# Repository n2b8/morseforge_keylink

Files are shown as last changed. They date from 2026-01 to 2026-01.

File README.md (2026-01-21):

# MorseForge Keylink

**Keylink** is an open‑source hardware adapter that makes traditional Morse keys Bluetooth‑capable.

It is designed and maintained by the **MorseForge developer** as a companion device for upcoming external‑key features in the **MorseForge** app.

🌐 **MorseForge:** https://morseforge.com

---

## What is Keylink?

Keylink bridges classic Morse key hardware with modern Bluetooth‑enabled devices. It allows straight keys, paddles, and other traditional Morse inputs to transmit key events wirelessly using Bluetooth Low Energy (BLE).

Keylink is intended to:
- Enable wireless Morse key input
- Integrate directly with future MorseForge app features
- Remain compact, battery‑powered, and easy to assemble
- Be fully open source and community‑friendly

Unlike generic microcontroller dev boards, Keylink is a **purpose‑built Morse interface**.

---

## Hardware Overview — Rev B

The current hardware revision (Rev B) includes:

- **ESP32‑C3 microcontroller (Seeed XIAO form factor)**
- **3.5 mm stereo jack (SJ1‑3523N)** for Morse key input
- **Slide power switch** for battery isolation
- **JST‑PH 2.0 mm battery connector**
- LiPo battery support
- Passive input conditioning network

This revision has been fabricated via OSH Park and is undergoing validation.

---

## PCB Renders (Rev B)

### Top View
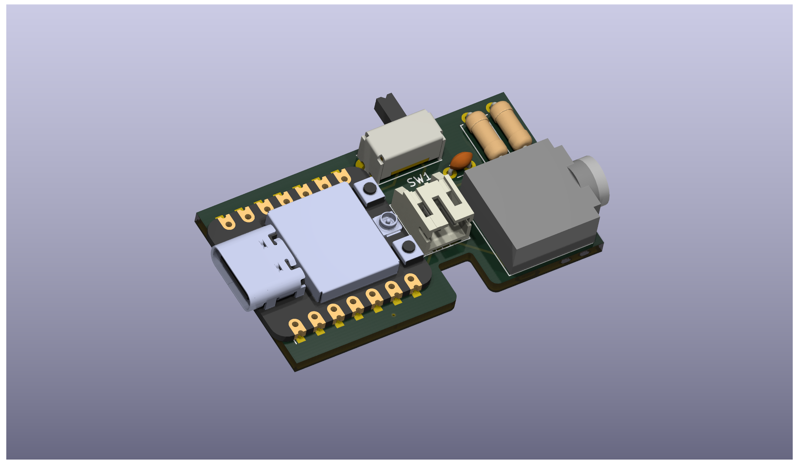
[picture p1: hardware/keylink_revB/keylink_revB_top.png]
Keylink Rev B Top


### Bottom View
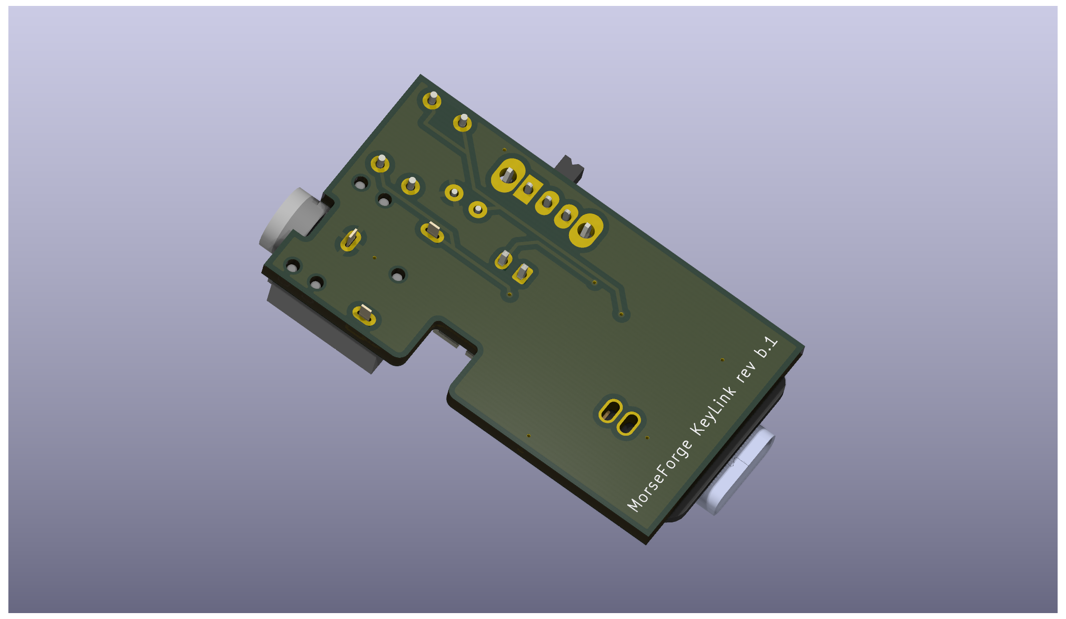
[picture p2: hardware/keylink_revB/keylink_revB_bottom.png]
Keylink Rev B Bottom


> Renders generated from KiCad’s 3D viewer. These are not production photographs.

---

## Repository Structure

```
hardware/
├── keylink_revB/     # KiCad schematic + PCB layout
├── gerber/           # Manufacturing Gerbers
mobile_app/           # React Native example app
software/             # Firmware (Arduino + legacy)
```

Additional firmware and software directories will be added as development progresses.

---

## Firmware & App Integration

Keylink firmware now uses the Arduino framework and exposes the device as a BLE
HID keyboard for Vail Adapter compatibility. The sketch lives at:
`software/keylink_ble_keyboard/keylink_ble_keyboard.ino`.

Key events:
- DIT (left paddle) sends Ctrl + [
- DAH (right paddle) sends Ctrl + ]

### Flashing (Arduino)

1. Install Arduino IDE and the ESP32 board package.
2. Install the "ESP32 BLE Keyboard" library (T-vK).
3. Open `software/keylink_ble_keyboard` in Arduino IDE.
4. Select board "Seeed XIAO ESP32C3" and flash.
5. Pair the device as "Keylink" in your OS Bluetooth settings.

The prior CircuitPython UART firmware remains at `software/code.py` for
reference but is not Vail-compatible.

---

## Open Source

This project is released as open‑source hardware and software.

Licensing details will be finalized and documented explicitly, but the intent is:
- **Permissive open hardware**
- **Permissive firmware licensing**
- Community contributions welcome

---

## Disclaimer

This is experimental hardware.

No warranties are provided.  
Use at your own risk.

---

## Author

Keylink is designed and maintained by the **MorseForge developer** as part of the broader MorseForge ecosystem.

🌐 https://morseforge.com

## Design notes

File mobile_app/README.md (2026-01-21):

# MorseForge Keylink Mobile App

Expo React Native app for receiving Morse key input from a BLE HID keyboard
(Keylink) and playing sidetone audio.

## Features

- External keyboard input (Ctrl+[ / Ctrl+]) from Keylink
- Real-time audio sidetone playback
- Straight + iambic keyer modes
- Event logging

## Setup

### 1. Install Dependencies

```bash
cd mobile_app
npm install
```

### 2. Run on iOS (Physical Device Required)

```bash
npx expo run:ios
```

**Note:** This app uses a native module (`react-native-external-keyboard`), so
Expo Go will not work. Use a dev build (see `BUILDING.md`).

### 3. Flash your Keylink device

Flash the Arduino firmware from:
`../software/keylink_ble_keyboard/keylink_ble_keyboard.ino`

### 4. Connect

1. Pair Keylink in your phone's Bluetooth settings (it appears as "Keylink").
2. Open the app and tap **Focus Input** if needed.
3. Press the paddles to hear tones.

## Configuration

### Keyer Modes

The app supports three keyer modes:
- **Straight Key**: Both paddles act as a simple straight key (continuous tone while pressed)
- **Iambic A**: Automatic alternating dits and dahs with paddle squeeze
- **Iambic B**: Enhanced iambic mode with improved squeeze behavior

Switch modes using the mode selector buttons in the app.

### Input Protocol

The firmware sends BLE HID key combos:
- DIT (left paddle): **Ctrl + [**
- DAH (right paddle): **Ctrl + ]**

The app listens for these external keyboard events using
`react-native-external-keyboard`.

### Tone Timing

Edit `App.js` to adjust:
- `DIT_MS = 60` - Duration of dit tone (milliseconds)
- `DAH_MS = 180` - Duration of dah tone (milliseconds)

## Building for Production

### iOS

1. Install EAS CLI:
```bash
npm install -g eas-cli
```

2. Configure EAS:
```bash
eas build:configure
```

3. Build for iOS:
```bash
eas build --platform ios
```

### Android

```bash
eas build --platform android
```

## Troubleshooting

### No key events
- Ensure Keylink is paired as a Bluetooth keyboard in system settings
- Tap **Focus Input** in the app to regain keyboard focus
- Verify the firmware is flashed and powered on

### No audio on key press
- Check phone is not in silent mode (iOS)
- Ensure `assets/tone.wav` exists
- Check console for audio initialization errors

## Project Structure

```
mobile_app/
├── App.js           # Main application code
├── app.json         # Expo configuration
├── package.json     # Dependencies
├── assets/
│   └── tone.wav     # Sidetone audio file
└── README.md        # This file
```

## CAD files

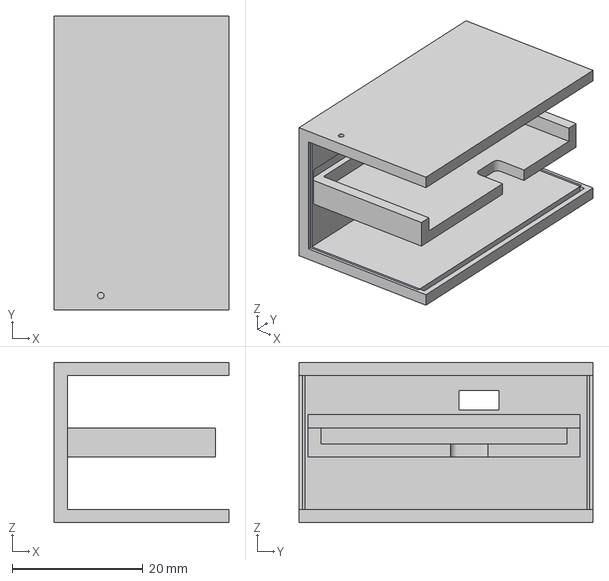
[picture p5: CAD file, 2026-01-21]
hardware/enclosure/printfiles/revB_case/Main_Housing.3mf
26.7 x 45.0 x 24.5 mm

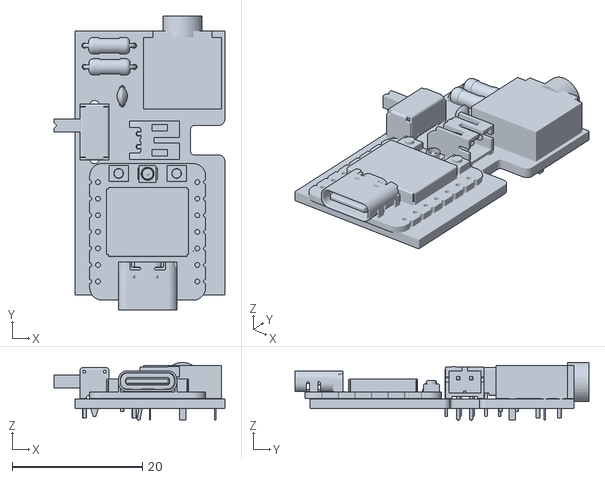
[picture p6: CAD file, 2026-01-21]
hardware/enclosure/keylink_revB.stl
26.2 x 45.1 x 8.90

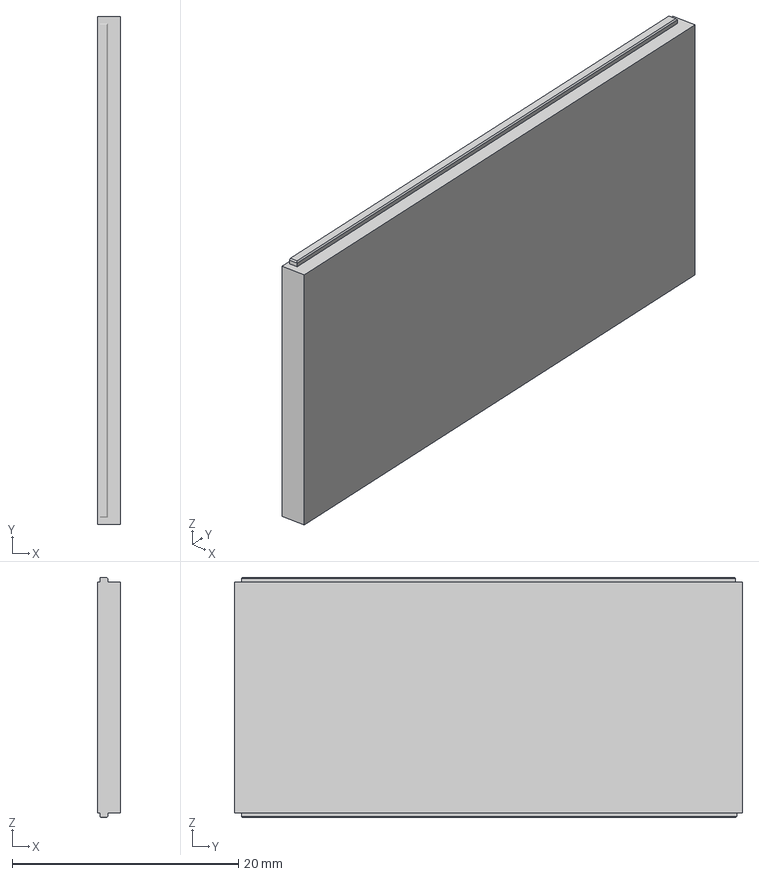
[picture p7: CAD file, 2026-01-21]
hardware/enclosure/printfiles/revB_case/Back.3mf
2.00 x 45.0 x 21.3 mm

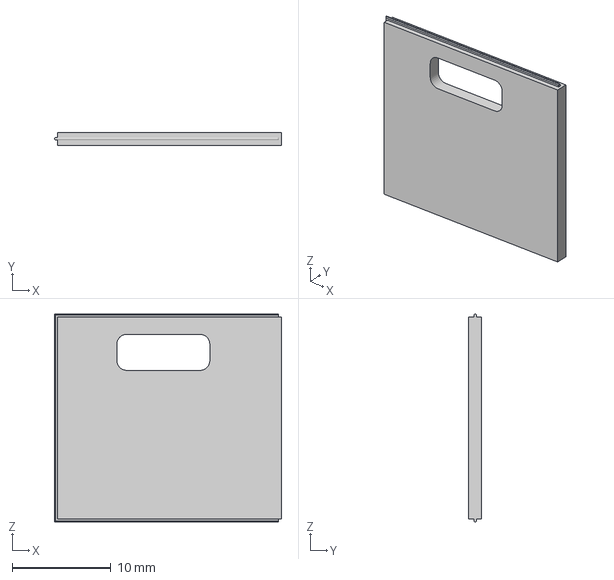
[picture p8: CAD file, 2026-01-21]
hardware/enclosure/printfiles/revB_case/USB_Side.3mf
23.0 x 1.35 x 21.1 mm

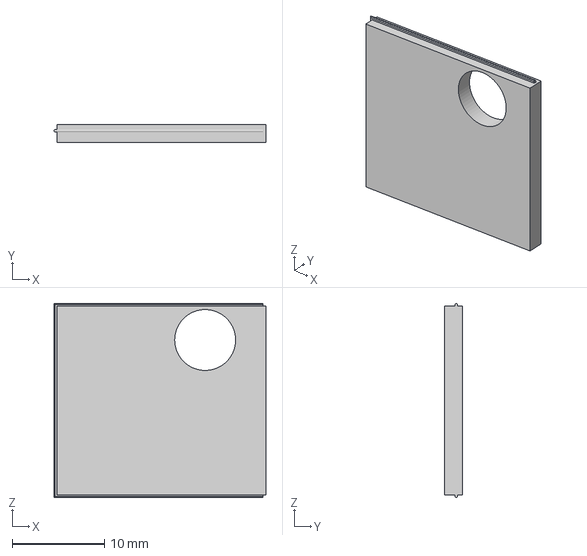
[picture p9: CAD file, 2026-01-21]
hardware/enclosure/printfiles/revB_case/TRS_Side.3mf
23.0 x 1.97 x 21.1 mm

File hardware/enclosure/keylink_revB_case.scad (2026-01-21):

// Keylink RevB - Parametric enclosure (Rev A)
// Units: mm

$fn = 48;

// -------------------- PARAMETERS --------------------
pcb_len = 40.0;        // measure from STEP
pcb_wid = 23.0;        // measure from STEP
pcb_thk = 1.6;

wall = 2.0;
floor = 2.0;

// Clearance
pcb_side_clear = 0.30; // per side
pcb_z_clear = 1.0;     // space above PCB plane before lid
rail_lip = 1.0;        // how much rail overlaps PCB edge
rail_height = pcb_thk + 0.3; // rail height above base floor

// Divider deck separating PCB and battery
deck_thk = 1.8;
deck_gap = 0.6;        // clearance between battery and deck (air gap)
pcb_to_deck = 1.0;     // space under PCB before deck (wires, solder)

// Battery (your candidate: 31 x 25 x 7)
bat_len = 31.0;
bat_wid = 25.0;
bat_thk = 7.0;
bat_clear_xy = 0.5;
bat_clear_z = 0.6;

// Case outer size
inner_len = pcb_len + 2*pcb_side_clear;
inner_wid = pcb_wid + 2*pcb_side_clear;

// Heights
pcb_plane_z = floor + pcb_to_deck + deck_thk + deck_gap + bat_thk + bat_clear_z;
inner_height = pcb_plane_z + pcb_thk + pcb_z_clear;   // interior height above floor
outer_height = inner_height + wall;

// End cutouts (placeholders - measure from STEP)
// USB-C at one end:
usbc_w = 10.0;
usbc_h = 4.0;
usbc_y_off = 0.0;      // offset from centerline if needed
// Audio jack at the other end:
jack_w = 8.0;
jack_h = 8.0;
jack_y_off = 0.0;

// Light pipe hole (measure LED XY from STEP)
// Coordinates relative to PCB origin at inside corner of case
led_x = 10.0;
led_y = 0.0;
lightpipe_d = 3.2;

// Battery side insert slot
slot_h = bat_thk + bat_clear_z + 1.0;
slot_w = bat_wid + bat_clear_xy;
slot_z = floor + 1.0; // from bottom

// -------------------- HELPERS --------------------
module rounded_box(x,y,z,r=2.0) {
  minkowski() {
    cube([x-2*r, y-2*r, z-2*r], center=false);
    sphere(r=r);
  }
}

module shell_base() {
  difference() {
    // Outer body
    rounded_box(inner_len + 2*wall, inner_wid + 2*wall, outer_height, r=2.0);

    // Hollow interior
    translate([wall, wall, floor])
      cube([inner_len, inner_wid, outer_height], center=false);
  }
}

module pcb_rails() {
  // Rails run along the long edges (length direction)
  // They form a channel the PCB slides into.
  rail_y0 = wall + pcb_side_clear;
  rail_y1 = wall + inner_wid - pcb_side_clear;

  // Left rail
  translate([wall, rail_y0 - rail_lip, pcb_plane_z])
    cube([inner_len, rail_lip, rail_height], center=false);

  // Right rail
  translate([wall, rail_y1, pcb_plane_z])
    cube([inner_len, rail_lip, rail_height], center=false);
}

module divider_deck() {
  // Deck across most of the case, leaving a battery region below
  translate([wall, wall, floor + pcb_to_deck])
    cube([inner_len, inner_wid, deck_thk], center=false);
}

module battery_pocket_cut() {
  // Pocket below the deck
  pocket_len = bat_len + bat_clear_xy;
  pocket_wid = bat_wid + bat_clear_xy;
  pocket_thk = bat_thk + bat_clear_z;

  // Put battery pocket centered, adjust if needed
  px = wall + (inner_len - pocket_len)/2;
  py = wall + (inner_wid - pocket_wid)/2;
  pz = floor;

  translate([px, py, pz])
    cube([pocket_len, pocket_wid, pocket_thk], center=false);
}

module battery_side_slot_cut() {
  // Slot through the case wall into battery pocket
  // Default: slot on the "right" side wall
  x0 = wall + (inner_len - (bat_len + bat_clear_xy))/2;
  y_wall = inner_wid + wall; // outer right wall
  z0 = slot_z;

  translate([x0, y_wall - 0.01, z0])
    cube([bat_len + bat_clear_xy, wall + 0.02, slot_h], center=false);
}

module end_cutouts() {
  // USB-C at +X end (front)
  translate([wall + inner_len - 0.01, wall + inner_wid/2 - usbc_w/2 + usbc_y_off, pcb_plane_z + pcb_thk/2 - usbc_h/2])
    cube([wall + 0.02, usbc_w, usbc_h], center=false);

  // Audio jack at -X end (back)
  translate([-0.01, wall + inner_wid/2 - jack_w/2 + jack_y_off, pcb_plane_z + pcb_thk/2 - jack_h/2])
    cube([wall + 0.02, jack_w, jack_h], center=false);
}

module lightpipe_cut() {
  // Hole through the lid area above the LED
  // LED position measured from inside corner (same orientation as PCB placement)
  lx = wall + pcb_side_clear + led_x;
  ly = wall + pcb_side_clear + led_y;
  lz = pcb_plane_z + pcb_thk + pcb_z_clear/2;

  translate([lx, ly, lz])
    rotate([90,0,0])
      cylinder(d=lightpipe_d, h=inner_wid + 2*wall, center=true);
}

// -------------------- BUILD --------------------
difference() {
  union() {
    shell_base();
    divider_deck();
    pcb_rails();
  }

  // Remove battery pocket volume
  battery_pocket_cut();

  // Battery insert slot
  battery_side_slot_cut();

  // End cutouts
  end_cutouts();

  // Lightpipe hole
  lightpipe_cut();
}

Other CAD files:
hardware/keylink_revB/keylink_revB.step
hardware/enclosure/U_Box_V104_Test_Cleaned.scad

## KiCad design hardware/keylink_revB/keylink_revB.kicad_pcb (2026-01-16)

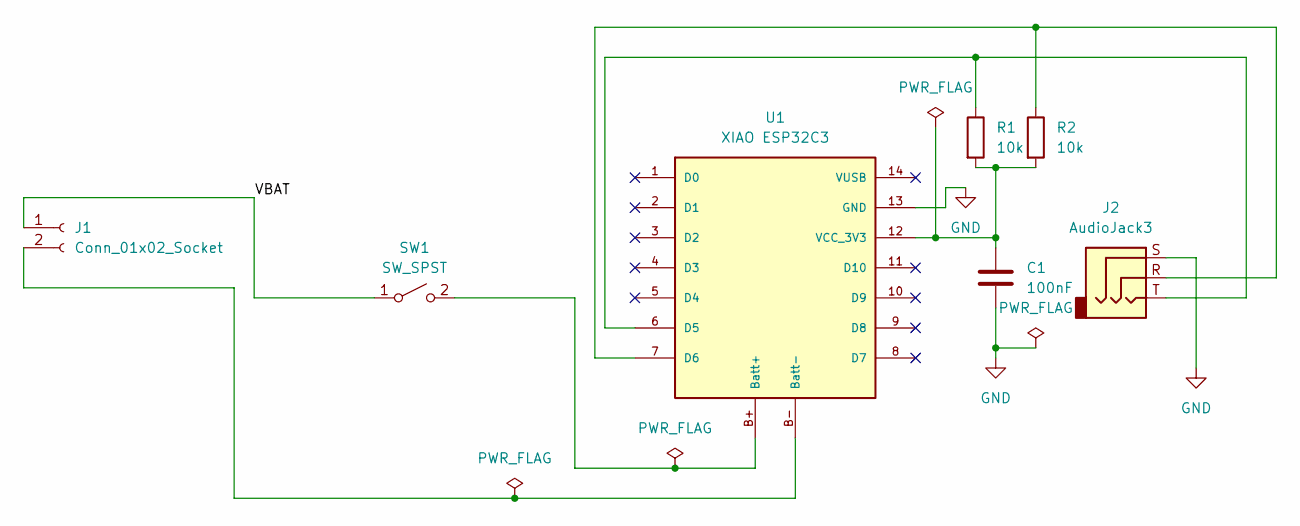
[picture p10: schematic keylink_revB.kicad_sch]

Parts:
C1: 100nF; C_Disc_D3.0mm_W1.6mm_P2.50mm
J1: Conn_01x02_Socket; JST_PH_S2B-PH-K_1x02_P2.00mm_Horizontal
J2: AudioJack3; Jack_3.5mm_CUI_SJ1-3523N_Horizontal
R1, R2: 10k; R_Axial_DIN0207_L6.3mm_D2.5mm_P7.62mm_Horizontal
SW1: SW_SPST; SW_Slide_SPDT_Angled_CK_OS102011MA1Q
U1: XIAO ESP32C3; xiao_esp32c3

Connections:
/VBAT: J1.1, SW1.1 (A)
GND: C1.2, J2.S, U1.13 (GND)
unnamed: J1.2, U1.B- (Batt-)
unnamed: SW1.2 (B), U1.B+ (Batt+)
unnamed: J2.T, R1.1, U1.6 (D5)
unnamed: J2.R, R2.1, U1.7 (D6)
unnamed: C1.1, R1.2, R2.2, U1.12 (VCC_3V3)

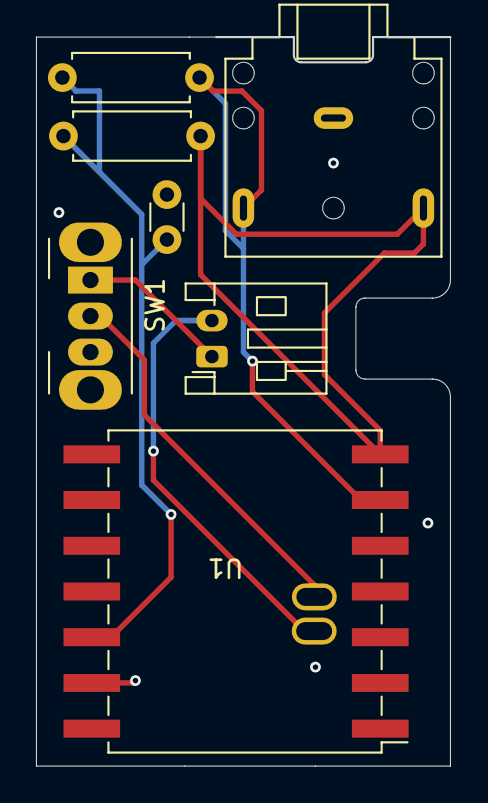
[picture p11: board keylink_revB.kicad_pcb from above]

Board: 2 copper layers, 23.0 x 40.5 mm, 7 parts (0 on the bottom side), 7 nets.

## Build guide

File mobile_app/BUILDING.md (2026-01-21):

# Building MorseForge Keylink for iOS and Android

Since this app uses native modules (external keyboard support), you cannot use
Expo Go. You need to create a development build.

## Option 1: Build Locally with Xcode (Recommended for Testing)

### Prerequisites
- Xcode installed
- iOS development certificate
- Your iPhone connected via USB

### Steps

1. Install iOS dependencies:
```bash
cd mobile_app
npx expo prebuild
```

2. Open the iOS project in Xcode:
```bash
open ios/mobileapp.xcworkspace
```

3. In Xcode:
   - Select your connected iPhone as the target device
   - Select your development team in Signing & Capabilities
   - Click the Play button to build and run

4. The app will install on your iPhone

## Option 2: Build with EAS (For Production)

### Prerequisites
- Expo account (free)
- EAS CLI installed

### Steps

1. Install EAS CLI:
```bash
npm install -g eas-cli
```

2. Login to Expo:
```bash
eas login
```

3. Configure EAS:
```bash
eas build:configure
```

4. Create a development build:
```bash
eas build --profile development --platform ios
```

5. When complete, scan the QR code with your iPhone to install

## Option 3: Quick Test with Expo Dev Client

1. Install expo-dev-client:
```bash
npx expo install expo-dev-client
```

2. Start development:
```bash
npx expo start --dev-client
```

3. Follow on-screen instructions to build and install on your device

## Android (Physical Device Required for External Keyboard Input)

1. Install dependencies:
```bash
cd mobile_app
npm install
```

2. Build and install on a connected device:
```bash
npx expo run:android
```

3. Pair Keylink as a Bluetooth keyboard in system settings

## Troubleshooting

### "Signing requires a development team"
- In Xcode, go to Signing & Capabilities
- Select your Apple ID team
- Xcode will automatically create a provisioning profile

### "Unable to install"
- Make sure your iPhone trusts your Mac
- Check that Developer Mode is enabled on iOS 16+ (Settings > Privacy & Security > Developer Mode)

### No key events
- Ensure Keylink is paired and connected as a keyboard
- Tap **Focus Input** in the app to regain keyboard focus

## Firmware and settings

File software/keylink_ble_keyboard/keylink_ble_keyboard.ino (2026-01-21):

#define USE_NIMBLE
#include <BleKeyboard.h>

// Keylink Rev B (Seeed XIAO ESP32C3)
// TRRS tip (left) -> GPIO7 (D5)
// TRRS ring (right) -> GPIO21 (D6)
const int DIT_PIN = 7;
const int DAH_PIN = 21;
const uint32_t DEBOUNCE_MS = 10;

const char DIT_KEY = '[';
const char DAH_KEY = ']';

BleKeyboard bleKeyboard("Keylink", "MorseForge", 100);

bool lastDitState = true;
bool lastDahState = true;
uint32_t lastDitChange = 0;
uint32_t lastDahChange = 0;

bool ditPressed = false;
bool dahPressed = false;
bool ctrlHeld = false;
bool lastConnected = false;

void resetKeyState() {
  ditPressed = false;
  dahPressed = false;
  ctrlHeld = false;
  bleKeyboard.releaseAll();
}

void applyConnectionState(bool connected) {
  if (connected == lastConnected) {
    return;
  }
  lastConnected = connected;
  if (!connected) {
    resetKeyState();
  }
}

void sendComboDown(char key) {
  if (!bleKeyboard.isConnected()) {
    return;
  }
  if (!ctrlHeld) {
    bleKeyboard.press(KEY_LEFT_CTRL);
    ctrlHeld = true;
  }
  bleKeyboard.press(key);
}

void sendComboUp(char key) {
  if (!bleKeyboard.isConnected()) {
    return;
  }
  bleKeyboard.release(key);
  if (!ditPressed && !dahPressed && ctrlHeld) {
    bleKeyboard.release(KEY_LEFT_CTRL);
    ctrlHeld = false;
  }
}

void setup() {
  Serial.begin(115200);
  pinMode(DIT_PIN, INPUT_PULLUP);
  pinMode(DAH_PIN, INPUT_PULLUP);
  bleKeyboard.begin();
}

void loop() {
  const bool connected = bleKeyboard.isConnected();
  applyConnectionState(connected);

  const uint32_t now = millis();

  const bool ditState = digitalRead(DIT_PIN);
  if (ditState != lastDitState && (now - lastDitChange) >= DEBOUNCE_MS) {
    lastDitChange = now;
    lastDitState = ditState;
    if (!ditState) {
      ditPressed = true;
      sendComboDown(DIT_KEY);
    } else {
      ditPressed = false;
      sendComboUp(DIT_KEY);
    }
  }

  const bool dahState = digitalRead(DAH_PIN);
  if (dahState != lastDahState && (now - lastDahChange) >= DEBOUNCE_MS) {
    lastDahChange = now;
    lastDahState = dahState;
    if (!dahState) {
      dahPressed = true;
      sendComboDown(DAH_KEY);
    } else {
      dahPressed = false;
      sendComboUp(DAH_KEY);
    }
  }

  delay(1);
}

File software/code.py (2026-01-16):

import time
import board
import digitalio

# BLE imports - requires adafruit_ble from the CircuitPython bundle
try:
    from adafruit_ble import BLERadio
    from adafruit_ble.advertising.standard import ProvideServicesAdvertisement
    from adafruit_ble.services.nordic import UARTService
    BLE_AVAILABLE = True
except ImportError:
    BLE_AVAILABLE = False
    print("WARNING: BLE libraries not found. Install adafruit_ble library bundle.")

# ----------------------------
# CONFIG (XIAO ESP32C3 PIN MAP)
# ----------------------------
# TRRS tip (left) -> GPIO7 (board.D5)
# TRRS ring (right) -> GPIO21 (board.D6)
DIT_PIN = board.D5     # TRRS TIP / left (GPIO7)
DAH_PIN = board.D6     # TRRS RING / right (GPIO21)
DEBOUNCE_S = 0.010     # 10ms debounce

# ----------------------------
# Optional onboard NeoPixel (no neopixel module needed)
# ----------------------------
PIXEL_ENABLED = True
PIXEL_PIN = getattr(board, "NEOPIXEL", None)
_pixel_io = None
_pixel_ok = False

def pixel_init():
    global _pixel_io, _pixel_ok
    if not PIXEL_ENABLED:
        return
    if PIXEL_PIN is None:
        return
    try:
        import neopixel_write  # type: ignore
        _pixel_io = digitalio.DigitalInOut(PIXEL_PIN)
        _pixel_io.direction = digitalio.Direction.OUTPUT
        _pixel_ok = True
    except Exception:
        _pixel_ok = False

def pixel_set(r: int, g: int, b: int):
    """Set pixel color. Most NeoPixels are GRB order."""
    if not _pixel_ok or not PIXEL_ENABLED:
        return
    import neopixel_write  # type: ignore
    r = max(0, min(255, r))
    g = max(0, min(255, g))
    b = max(0, min(255, b))
    neopixel_write.neopixel_write(_pixel_io, bytes([g, r, b]))

def pixel_off():
    pixel_set(0, 0, 0)

def ms() -> int:
    return int(time.monotonic() * 1000)

# ----------------------------
# Setup inputs (active-low with pullups)
# ----------------------------
dit = digitalio.DigitalInOut(DIT_PIN)
dit.direction = digitalio.Direction.INPUT
dit.pull = digitalio.Pull.UP

dah = digitalio.DigitalInOut(DAH_PIN)
dah.direction = digitalio.Direction.INPUT
dah.pull = digitalio.Pull.UP

last_dit = dit.value
last_dah = dah.value
last_change_dit = time.monotonic()
last_change_dah = time.monotonic()

pixel_init()
pixel_set(0, 0, 12)  # dim blue idle (if pixel is available)

# ----------------------------
# BLE Setup
# ----------------------------
ble = None
uart = None
advertisement = None
if BLE_AVAILABLE:
    ble = BLERadio()
    ble.name = "MorseKey"
    uart = UARTService()
    advertisement = ProvideServicesAdvertisement(uart)
    # Keep the device name in the primary advertisement for iOS discovery.
    advertisement.complete_name = ble.name
    print(f"Advertisement services: {advertisement.services}")

last_connected = False
last_uart_error = 0.0

def ble_is_connected() -> bool:
    return bool(BLE_AVAILABLE and ble and ble.connected)

def safe_uart_write(event_text: str) -> None:
    global last_uart_error
    if not ble_is_connected():
        return
    try:
        uart.write((event_text + "\n").encode("utf-8"))
    except Exception as exc:
        now = time.monotonic()
        if (now - last_uart_error) > 2.0:
            print("UART write failed:", repr(exc))
            last_uart_error = now

print("=== MorseForge TRRS + BLE (Seeed XIAO ESP32C3) ===")
print("DIT pin:", DIT_PIN)
print("DAH pin:", DAH_PIN)
print("Debounce:", int(DEBOUNCE_S * 1000), "ms")
if BLE_AVAILABLE:
    print("BLE Name:", ble.name)
    print("Starting BLE advertising...")
    ble.start_advertising(advertisement)
    print("Ready. Press paddles/key...")
else:
    print("BLE not available - running in serial-only mode")
    print("Ready. Press paddles/key...")

# ----------------------------
# Main loop
# ----------------------------
while True:
    now = time.monotonic()

    # Check for BLE connection changes
    if BLE_AVAILABLE and ble:
        connected_now = ble.connected
        if connected_now != last_connected:
            last_connected = connected_now
            if connected_now:
                print("BLE connected.")
                pixel_set(12, 0, 12)  # purple = connected
            else:
                print("BLE disconnected.")
                if not ble.advertising:
                    print("Restarting BLE advertising...")
                    ble.start_advertising(advertisement)
                pixel_set(0, 0, 12)  # idle blue

    # DIT edge detect with debounce
    cur_dit = dit.value
    if cur_dit != last_dit and (now - last_change_dit) >= DEBOUNCE_S:
        last_change_dit = now
        last_dit = cur_dit

        if not cur_dit:
            # Key pressed (active low)
            event = "K1:1"  # Key 1 (dit/left paddle) pressed
            print(f"{ms()} DIT_DOWN")
            pixel_set(0, 20, 0)   # green
            safe_uart_write(event)
        else:
            # Key released
            event = "K1:0"  # Key 1 (dit/left paddle) released
            print(f"{ms()} DIT_UP")
            if BLE_AVAILABLE and ble and ble.connected:
                pixel_set(12, 0, 12)
            else:
                pixel_set(0, 0, 12)
            safe_uart_write(event)

    # DAH edge detect with debounce
    cur_dah = dah.value
    if cur_dah != last_dah and (now - last_change_dah) >= DEBOUNCE_S:
        last_change_dah = now
        last_dah = cur_dah

        if not cur_dah:
            # Key pressed (active low)
            event = "K2:1"  # Key 2 (dah/right paddle) pressed
            print(f"{ms()} DAH_DOWN")
            pixel_set(0, 0, 20)   # blue brighter
            safe_uart_write(event)
        else:
            # Key released
            event = "K2:0"  # Key 2 (dah/right paddle) released
            print(f"{ms()} DAH_UP")
            if BLE_AVAILABLE and ble and ble.connected:
                pixel_set(12, 0, 12)
            else:
                pixel_set(0, 0, 12)
            safe_uart_write(event)

    time.sleep(0.001)

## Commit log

2026-01-10 Prototype device software completed
    [keylink_custom.kicad_pcb, keylink_custom.kicad_sch]
2026-01-10 Starting custom pcb design
    [keylink_custom.kicad_sch, morseforge_keylink_revA.kicad_pcb, morseforge_keylink_revA.kicad_sch]
2026-01-10 PCB schematic USB-C power input block
    [morseforge_keylink_revA.kicad_sch]
2026-01-10 PCB BMS
    [morseforge_keylink_revA.kicad_sch]
2026-01-10 Fixed wire from BAT to VBAT
    [morseforge_keylink_revA.kicad_sch]
2026-01-10 USB-UART blocks
2026-01-10 Add BLE functionality to firmware and create mobile app
    - Updated code.py with BLE UART service for morse key events
    - Created Expo React Native mobile app with BLE connectivity
    - App connects to ESP32, receives DIT/DAH events, plays audio sidetone
    - Configured iOS/Android BLE permissions
    - Added tone.wav audio asset
    - Includes setup documentation in mobile_app/README.md
    [morseforge_keylink_revA.kicad_sch]
2026-01-10 Update firmware for CircuitPython BLE compatibility and cleanup
    - Added try/except for adafruit_ble imports with fallback to serial-only mode
    - Code now gracefully handles missing BLE libraries
    - Removed mobile_app_example directory (consolidated into mobile_app)
    - Firmware will work with or without BLE libraries installed
    - To use BLE: Install adafruit_ble library bundle from CircuitPython library bundle
    [code.py]
2026-01-10 Fix BLE scan and connection flow
    [code.py]
2026-01-10 Adding reset and boot buttons
    [morseforge_keylink_revA.kicad_sch]
2026-01-10 Adding in esp32
    [morseforge_keylink_revA.kicad_sch]
2026-01-16 rev b board, much simpler
    [keylink_revB.kicad_pcb, keylink_revB.kicad_sch, morse_ble_trainer.kicad_pcb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]
2026-01-16 Adding the pull up resistor footprints
    [keylink_revB.kicad_sch]
2026-01-16 pcb layout completed
    [keylink_revB.kicad_pcb, keylink_revB.kicad_sch]
2026-01-16 Finalized revB.1 pcb
    [keylink_revB-B_Cu.gbr, keylink_revB-B_Mask.gbr, keylink_revB-B_Silkscreen.gbr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]
2026-01-16 Add .gitignore for KiCad and OS clutter
    [morse_ble_trainer.kicad_pcb, morse_ble_trainer.kicad_sch, morseforge_keylink_revA.kicad_pcb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]
2026-01-16 Update XIAO ESP32C3 pin mapping
2026-01-21 Update hardware enclosure and KiCad assets
    [Back.3mf, Main_Housing.3mf, TRS_Side.3mf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]
